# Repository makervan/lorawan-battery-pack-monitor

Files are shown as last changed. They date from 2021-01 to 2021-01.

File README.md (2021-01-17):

# LoRaWAN Battery Pack Monitor
The LoRaWAN Battery Pack Monitor is a LoRaWAN connected device based on the ATMega328 LoRaWAN Node to automatically measure the individual cell voltages of a Lithium Ion battery pack (up to 7S).

Find more details in the [MakerVan Labs Wiki](https://wiki.makervan.de/wiki/LoRaWAN_Battery_Monitor)

## License
* Licensed under Creative Commons Attribution-ShareAlike 4.0 Unported License (CC BY-SA 4.0)
* [Severin Schols](https://github.com/tiefpunkt)

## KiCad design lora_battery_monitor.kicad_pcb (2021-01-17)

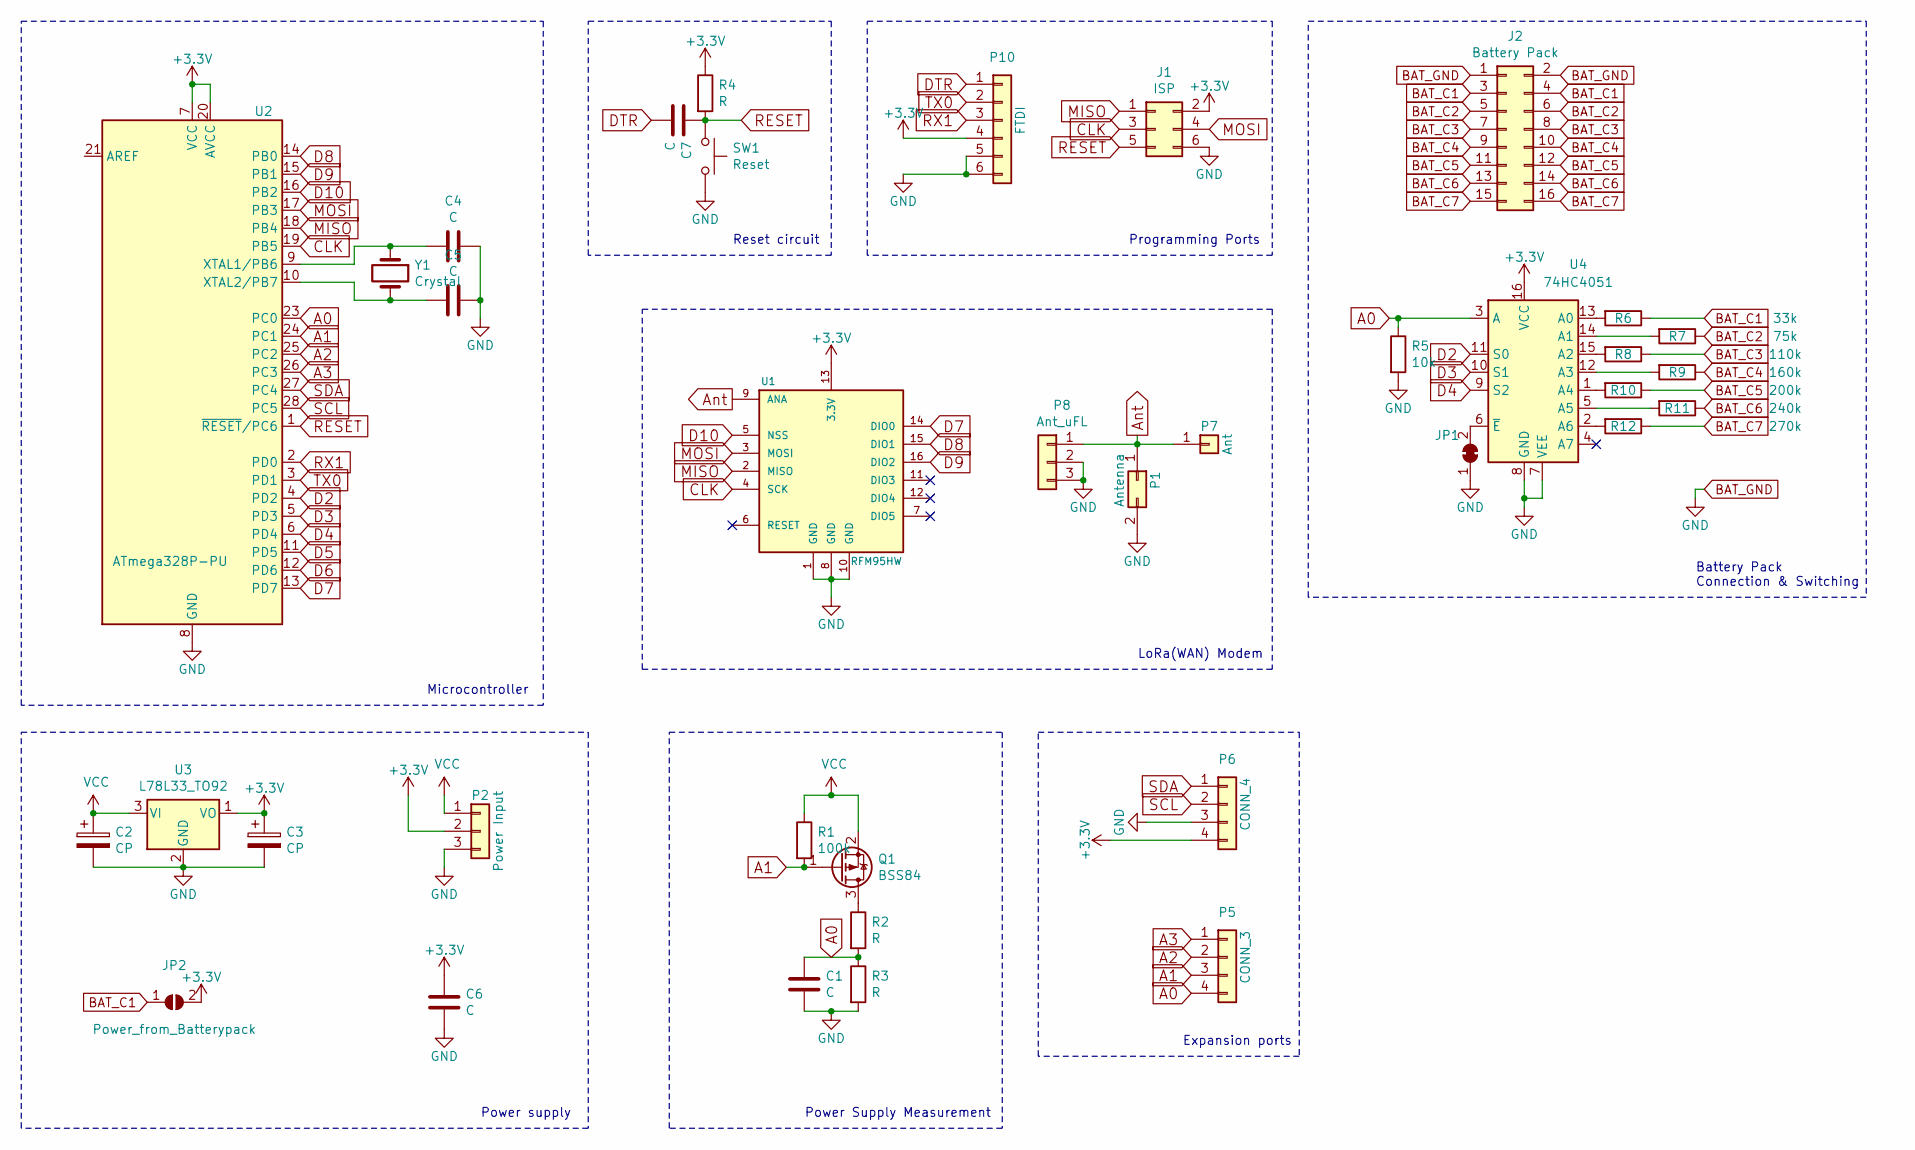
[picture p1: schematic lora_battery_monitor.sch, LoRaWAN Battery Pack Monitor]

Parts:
C1, C4, C5, C6, C7: C; C_0805_2012Metric_Pad1.15x1.40mm_HandSolder
C2, C3: CP; CP_Radial_D5.0mm_P2.50mm
J1: ISP; PinHeader_2x03_P2.54mm_Vertical
J2: Battery Pack; IDC-Header_2x08_P2.54mm_Vertical
JP1: Enable_jumper; SolderJumper-2_P1.3mm_Bridged_RoundedPad1.0x1.5mm
JP2: Power_from_Batterypack; SolderJumper-2_P1.3mm_Open_RoundedPad1.0x1.5mm
P1: Antenna; SMA_EDGE
P2: Power Input; PINHEAD1-3
P5: CONN_3; Pin_Header_Straight_1x04
P6: CONN_4; Pin_Header_Straight_1x04
P7: Ant; PINTST
P8: Ant_uFL; U.FL-COAX
P10: FTDI; PinHeader_1x06_P2.54mm_Vertical
Q1: BSS84; SOT-23
R1: 100k; R_0805_2012Metric_Pad1.15x1.40mm_HandSolder
R2, R3, R4: R; R_0805_2012Metric_Pad1.15x1.40mm_HandSolder
R5: 10k; R_0805_2012Metric_Pad1.20x1.40mm_HandSolder
R6: 33k; R_0805_2012Metric_Pad1.20x1.40mm_HandSolder
R7: 75k; R_0805_2012Metric_Pad1.20x1.40mm_HandSolder
R8: 110k; R_0805_2012Metric_Pad1.20x1.40mm_HandSolder
R9: 160k; R_0805_2012Metric_Pad1.20x1.40mm_HandSolder
R10: 200k; R_0805_2012Metric_Pad1.20x1.40mm_HandSolder
R11: 240k; R_0805_2012Metric_Pad1.20x1.40mm_HandSolder
R12: 270k; R_0805_2012Metric_Pad1.20x1.40mm_HandSolder
SW1: Reset; SW_PUSH_6mm
U1: RFM95HW; RFM69HW_SMD_Handsoldering-Narrow
U2: ATmega328P-PU; DIP-28_W7.62mm
U3: L78L33_TO92; TO-92_Inline
U4: 74HC4051; SO-16_3.9x9.9mm_P1.27mm
Y1: Crystal; Crystal_HC49-U_Vertical

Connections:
+3V3: C3.1, C6.2, J1.2, JP2.2 (B), P2.2, P6.4, P10.4, R4.1, U1.13 (3.3V), U2.7 (VCC), U2.20 (AVCC), U3.1 (VO), U4.16 (VCC)
A0: C1.1, P5.4, R2.2, R3.1, R5.1, U2.23 (PC0), U4.3 (A)
A1: P5.3, Q1.1 (G), R1.2, U2.24 (PC1)
A2: P5.2, U2.25 (PC2)
A3: P5.1, U2.26 (PC3)
Ant: P1.1, P7.1, P8.1, U1.9 (ANA)
BAT_C1: J2.3, J2.4, JP2.1 (A), R6.1
BAT_C2: J2.5, J2.6, R7.1
BAT_C3: J2.7, J2.8, R8.1
BAT_C4: J2.9, J2.10, R9.1
BAT_C5: J2.11, J2.12, R10.1
BAT_C6: J2.13, J2.14, R11.1
BAT_C7: J2.15, J2.16, R12.1
BAT_GND: C1.2, C2.2, C3.2, C4.1, C5.1, C6.1, J1.6, J2.1, J2.2, JP1.1 (A), P1.2, P2.3, P6.3, P8.2, P8.3, P10.5, P10.6, R3.2, R5.2, SW1.2, U1.1 (GND), U1.8 (GND), U1.10 (GND), U2.8 (GND), U2.22 (GND), U3.2 (GND), U4.7 (VEE), U4.8 (GND)
CLK: J1.3, U1.4 (SCK), U2.19 (PB5)
D2: U2.4 (PD2), U4.11 (S0)
D3: U2.5 (PD3), U4.10 (S1)
D4: U2.6 (PD4), U4.9 (S2)
D5: U2.11 (PD5)
D6: U2.12 (PD6)
D7: U1.14 (DIO0), U2.13 (PD7)
D8: U1.15 (DIO1), U2.14 (PB0)
D9: U1.16 (DIO2), U2.15 (PB1)
D10: U1.5 (NSS), U2.16 (PB2)
DTR: C7.1, P10.1
MISO: J1.1, U1.2 (MISO), U2.18 (PB4)
MOSI: J1.4, U1.3 (MOSI), U2.17 (PB3)
unnamed: C4.2, U2.9 (XTAL1/PB6), Y1.1
unnamed: C5.2, U2.10 (XTAL2/PB7), Y1.2
unnamed: JP1.2 (B), U4.6 (~E)
unnamed: Q1.3 (D), R2.1
unnamed: R6.2, U4.13 (A0)
unnamed: R7.2, U4.14 (A1)
unnamed: R8.2, U4.15 (A2)
unnamed: R9.2, U4.12 (A3)
unnamed: R10.2, U4.1 (A4)
unnamed: R11.2, U4.5 (A5)
unnamed: R12.2, U4.2 (A6)
RESET: C7.2, J1.5, R4.2, SW1.1, U2.1 (~RESET~/PC6)
RX1: P10.3, U2.2 (PD0)
SCL: P6.2, U2.28 (PC5)
SDA: P6.1, U2.27 (PC4)
TX0: P10.2, U2.3 (PD1)
VCC: C2.1, P2.1, Q1.2 (S), R1.1, U3.3 (VI)

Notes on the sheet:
Microcontroller
Reset circuit
Programming Ports
LoRa(WAN) Modem
Power supply
Power Supply Measurement
Battery Pack Connection & Switching
Expansion ports

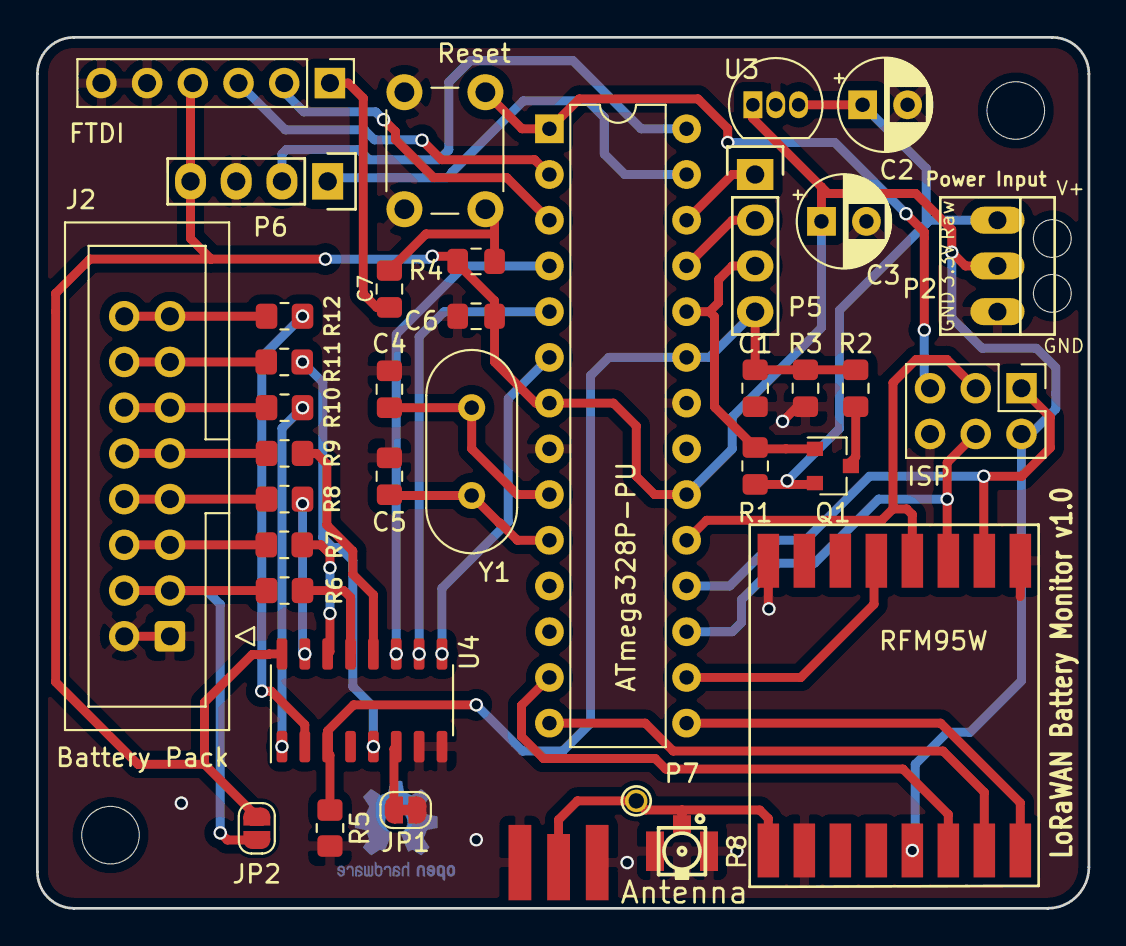
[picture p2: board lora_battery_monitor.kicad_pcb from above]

Board: 2 copper layers, 58.4 x 48.4 mm, 37 parts (0 on the bottom side), 42 nets.
